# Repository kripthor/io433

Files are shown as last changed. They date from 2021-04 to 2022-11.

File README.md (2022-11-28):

# Project IO433

```
 ___ ___  _ _ ________
|_ _/ _ \| | |__ /__ /
 | | (_) |_  _|_ \|_ \
|___\___/  |_|___/___/
                       
```

## Description

IO433 is an open-source ESP32 (TTGO T-Display) & CC1101 based 433Mhz sniffer. It is currently work in progress.
It can sniff, store, replay, dump and monitor most 433Mhz (currently ASK-OOK only) signals.
These include garage door openers, remote doorbells, sensors and similar devices.

The core of this project aims to be its simplicity, reliability and versatility.
With a couple of ICs and a by 'connecting some wires', or soldering a breakout board, one can start messing around with 433Mhz devices and decode their communications protocols.
It's mainly a proof-of-concept but already encompasses several very useful features.

```bash
│  # The current dir is a platformIO project and can be imported straight from here.
├── arduino  # an example arduino project that implements a remote for some ASK-OOK-PWM signals based on a FS1000A
├── docs     # docs and pictures
├── include  # project helper files 
├── lib    #some needed libraries with specific modifications for this project
├── libsigrokdecode   # a modified PWM decoder that shows bits and nibbles (sigrok/PulseView)
└── src # project main files
```

## Bill of Materials

| Qty. | Description | Obs. |
|---|---|---|
| 1 | ESP32 TTGO T-Display | ESP32 controller with a 1.14" LCD and two buttons for navigation |
| 1 | TI-CC1101 or E07-M1101D | CC1101 based modules for 433Mhz (and other frequencies) communications |
| 1 | io433 PCB| Order a PCB or etch one or just grab some wires :) |
| 1 | Battery | Optional 3.7v battery

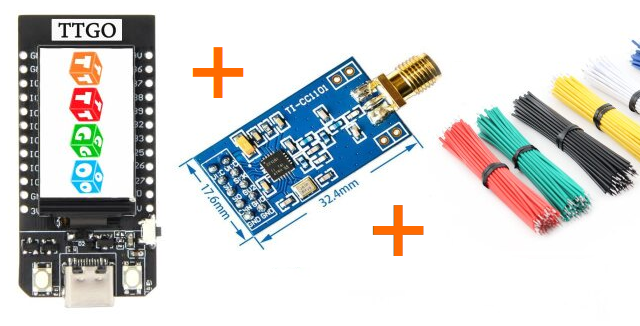
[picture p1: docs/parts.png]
IO433 Parts

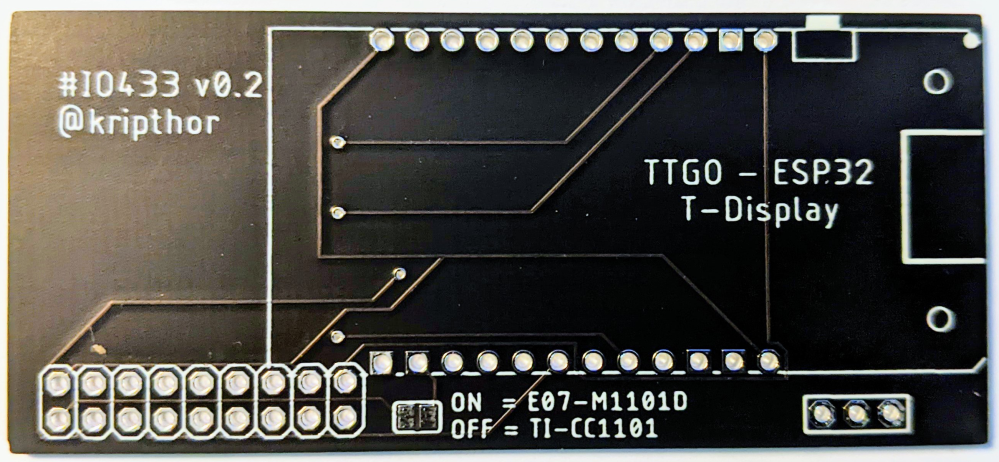
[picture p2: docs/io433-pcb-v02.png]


* All the components can be easily found in the usual online stores such as *AliExpress* ([ESP32 TTGO T-Display](https://aliexpress.com/wholesale?SearchText=ttgo+t+display+esp32)) - [CC1101](https://aliexpress.com/wholesale?SearchText=cc1101)), *Amazon*, *eBay*, etc.
* The breakout pcb and schematics files are under the docs/ directory: 
[IO433 Schematic](docs/breakout.sch)
[IO433 Board](docs/breakout.brd)

## IO433 Wiring

### Prototype photo and assembly suggestion

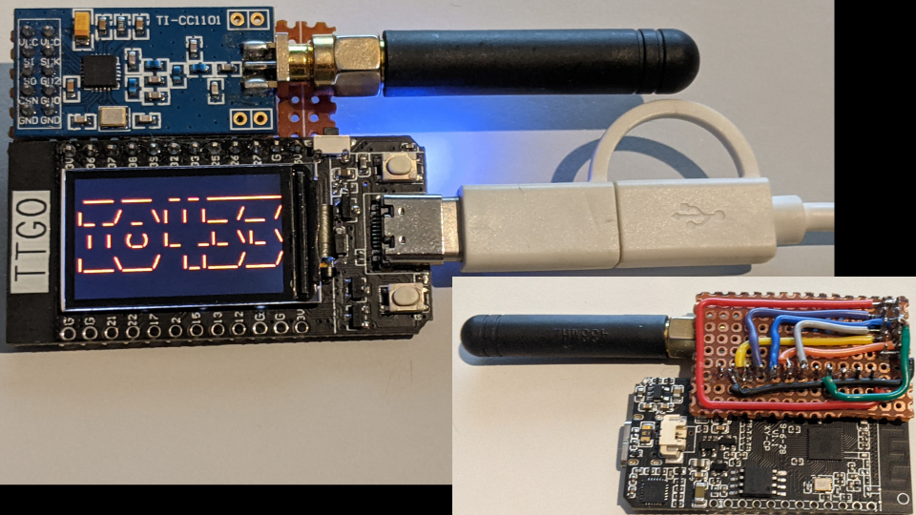
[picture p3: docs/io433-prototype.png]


This is just a suggestion on how to wire the ESP32 and the CC1101. A perforated PCB can be used to make the prototype more sturdy. Or you can just order a pre-fabricated board, like the one bellow:

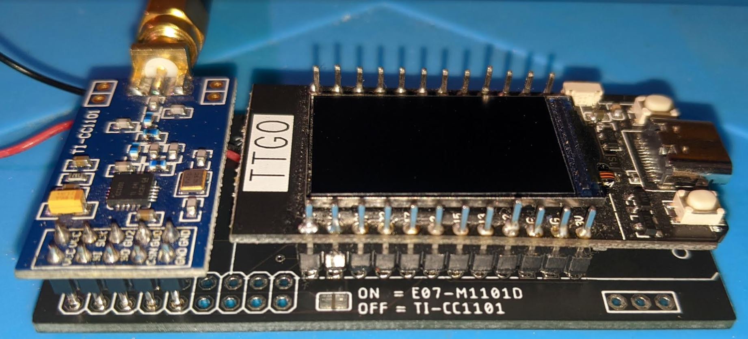
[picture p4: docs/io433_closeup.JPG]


### IO433 Wiring

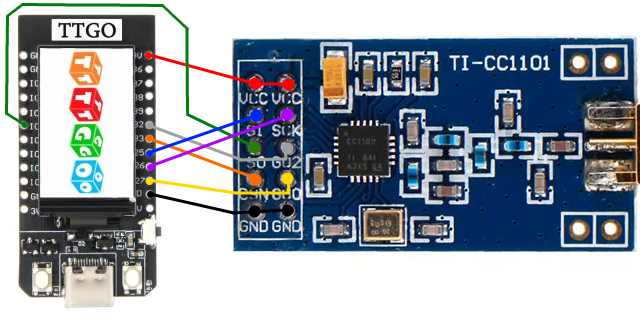
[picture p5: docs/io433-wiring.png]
IO433 Wiring

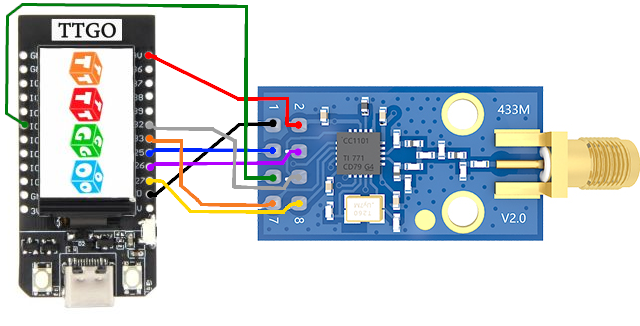
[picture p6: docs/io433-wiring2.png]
IO433 Wiring


Details of the wiring between the ESP32 and TI-CC1101 (above) and the E07-M1101D (below). The pinout choosing is important. If changed, not only the code should change to reflect the new pinout, as one must make sure the corresponding ports on the ESP32 support the I/O operation mode that the code needs. 
* **Important note**: the green wire connects to IO2 on the ESP32, regardless of what you see in some pictures.
* **Important note 2**: You need to change the file ./include/CC1101utils.h to reflect which CC1101 model you are using.

### IO433 PCB Schematics
docs/breakout.sch
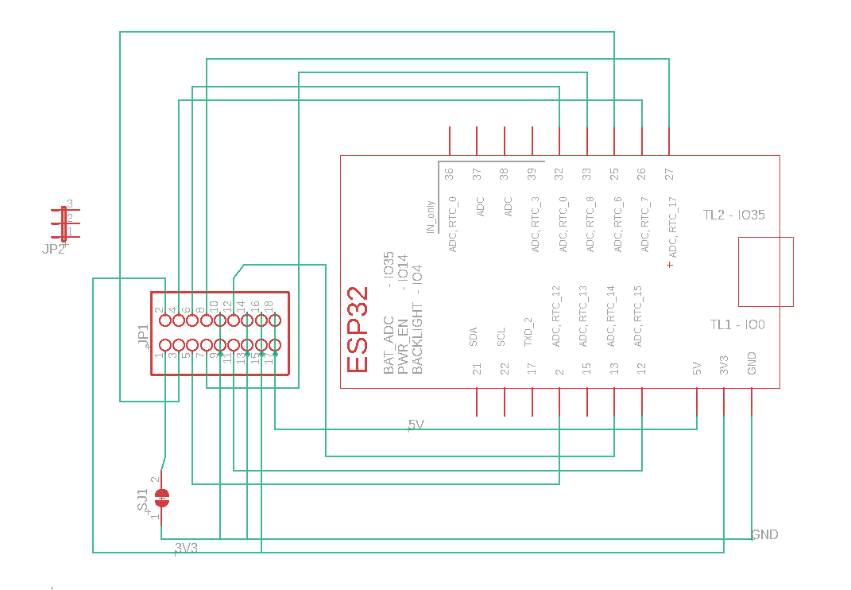
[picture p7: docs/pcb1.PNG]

docs/breakout.brd
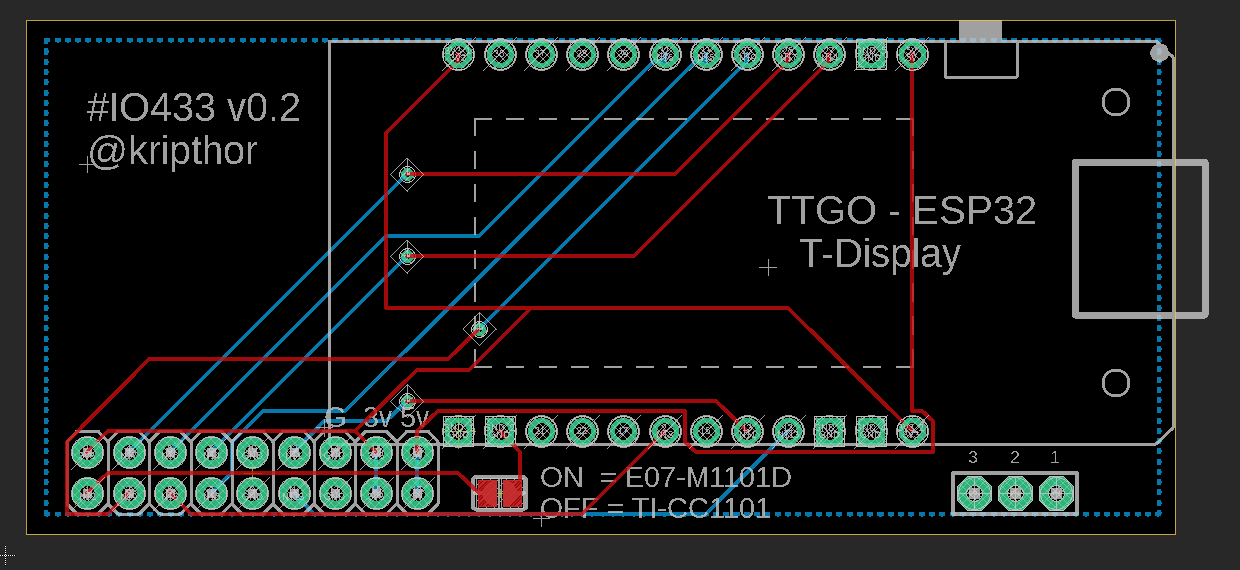
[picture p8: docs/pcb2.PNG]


### Assembly with PCB

Solder the CC1101 based module in the lower leftmost side of the pcb. The E07-M1101D will have 2x4 pins and the TI-CC1101 will have 2x5 pins. If you are using the E07-M1101D, connect the solderable jumper in the lower middle.  

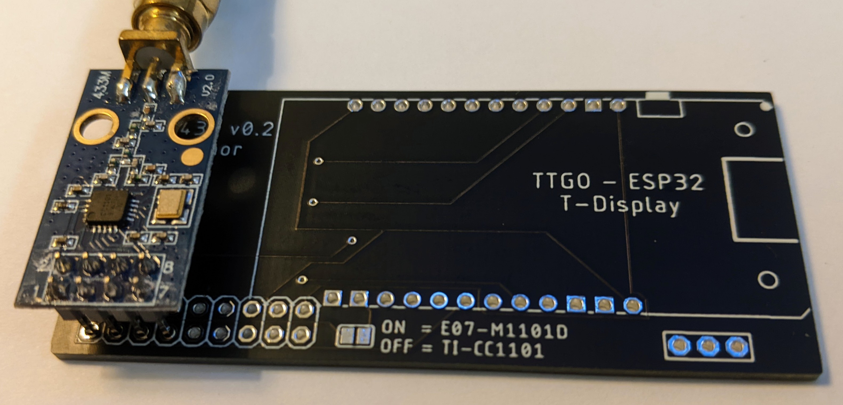
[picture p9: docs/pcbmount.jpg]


Then just solder the ESP32 TTGO module on the PCB. Add a battery or just use the USB cable to power the module. Optionally print the 3D case for your CC1101 module. 
I've made an Youtube video to show how to assemble it in less than half an hour: [IO433 Assembly on Youtube](https://www.youtube.com/watch?v=Nz-Mw6mhYjg)

### Assembly with battery and 3D printed case, no PCB

If you want, you can use the 3D printed case that supports a 902540 720mAh or even a 903048 1800mAh, 3.7V battery (should last for some days)
The full material is listed bellow:

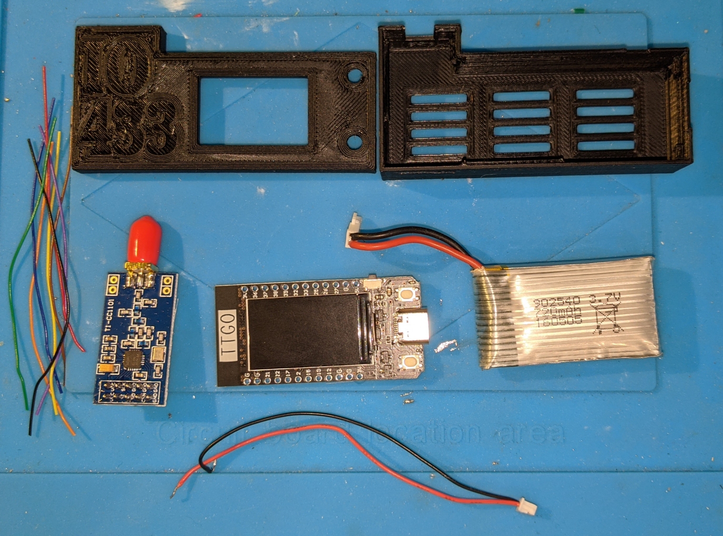
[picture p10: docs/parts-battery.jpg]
IO433 3D case with battery

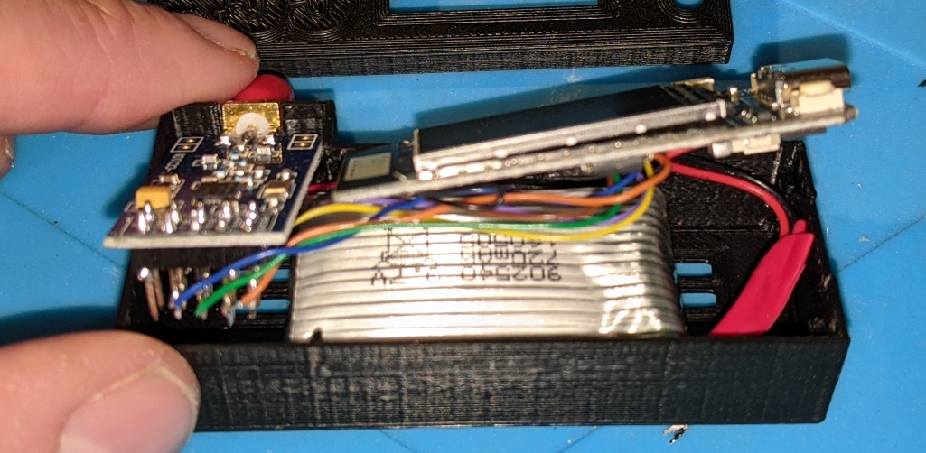
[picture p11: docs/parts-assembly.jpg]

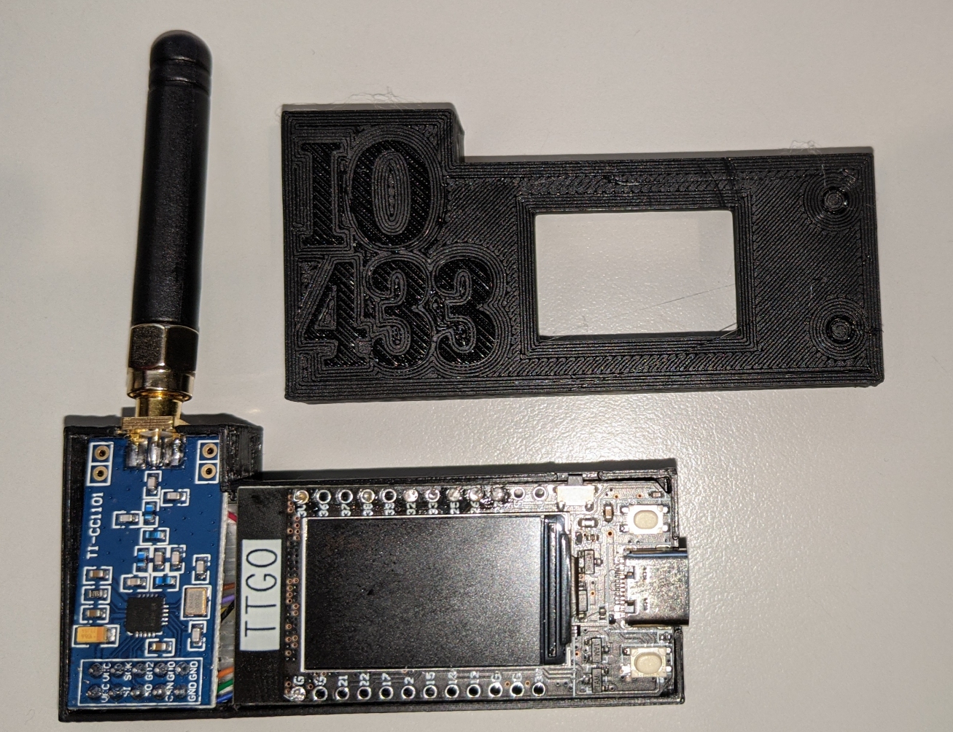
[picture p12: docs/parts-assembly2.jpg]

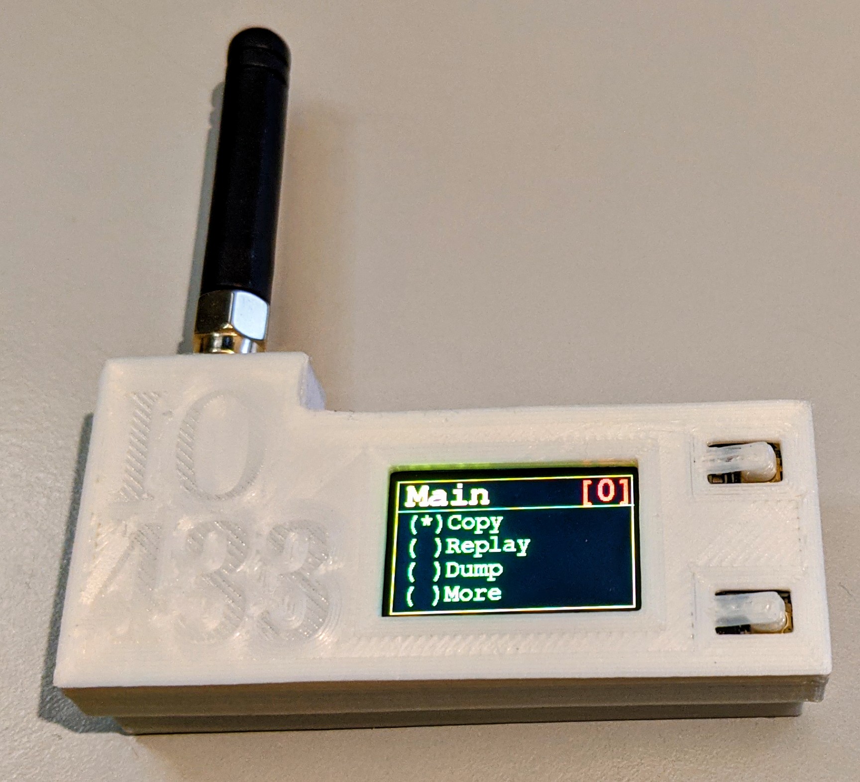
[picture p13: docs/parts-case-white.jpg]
IO433 3D case with battery


### 3D case

NO PCB version:
Tinker/download it from [tinkercad](https://www.tinkercad.com/things/bPiFpUXC7pQ)
or grab the STL from the [docs](docs/IO433.stl)

PCB Version:
Tinker/download, both TI-CC1101 and E07-M1101 versions, from  [tinkercad](https://www.tinkercad.com/things/0qDgP6hPqE1)

## How to flash IO433   

### Using [Platformio](https://platformio.org/)

* Install Visual Studio
* Install PlatformIO from the Extensions (restart)
* Install the Espressif 32 platform from the PlatformIO Embedded tab (restart)
* Clone the repository
* Change the file ./include/CC1101utils.h and uncomment your CC1101 version(either the TICC1101 or the E07M1101D)
* Connect USB-C cable to TTGO
* Build and upload

## How to use it

Plug the ESP32 to a battery or a to a USB-C cable. The current menu structure is the following:

```bash
│ Main
├── Copy   # Copy signal to current memory bank
├── Replay # Replay signal from current memory bank
├── Dump   # Dump current memory bank to screen and serial (fixed 100kbps, for easy analysis on third party software [ex. PulseView])
└── More
    ├── Monitor # Dump raw signal to screen and RSSI info
    ├── Raw Out # Dump current signal to serial as fast as possible (default 1Mbps serial)
    └── About   # About menu
```

## Button behaviour

* UP and DOWN short press, moves between menu items
* UP long press is moves back a level
* DOWN long press enters current submenu or function
* UP or DOWN double press moves back and forward from memory banks (to store/replay multiple signals) 

## Dependencies

This project uses:

 * Button2 lib (which should auto-update on build via platformio.ini)
 * SmartRC-CC1101-Driver-Lib (on /lib, added minor changes for the ESP32 TDisplay)
 * TFT_eSPI (on /lib, added minor changes for the ESP32 TDisplay)

# Improvements

There are many possibilities for improvements:

* Code refactoring. Make SimpleMenu a proper lib.
* Better SPIFFS management
* Configuration menus for changing output data rates and formats
* Configuration menus for CC1101 setup: frequencies, modulations, data rates and bandwidth
* Implement other modulations besides ASK-OOK
* Add upload data files from PC to be replayed
* Add accept from serial and transmit features
* and so forth...

Feel free to clone and play around, as well as to contribute and make a pull request.

## Kudos

* [LSatan](https://github.com/LSatan), for the SmartRC-CC1101-Driver-Lib
* the [TFT_eSPI Library](https://github.com/Bodmer/TFT_eSPI)
* Shameless README.md 'template' rip from [jpdias](https://github.com/jpdias)

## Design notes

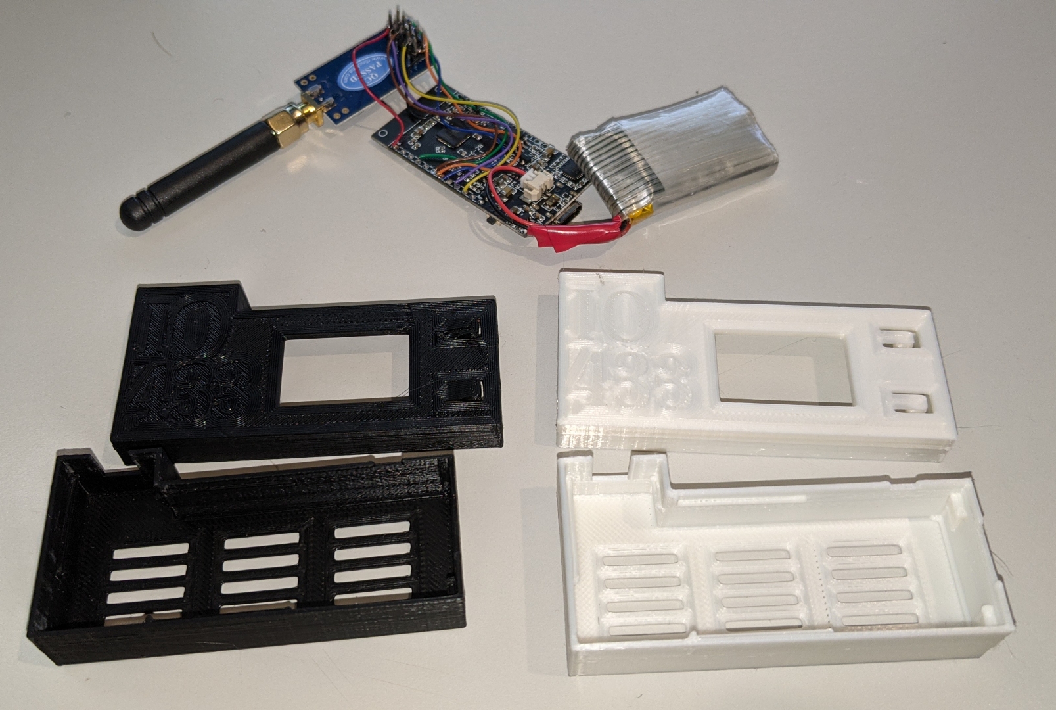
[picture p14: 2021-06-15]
docs/two-cases.jpg

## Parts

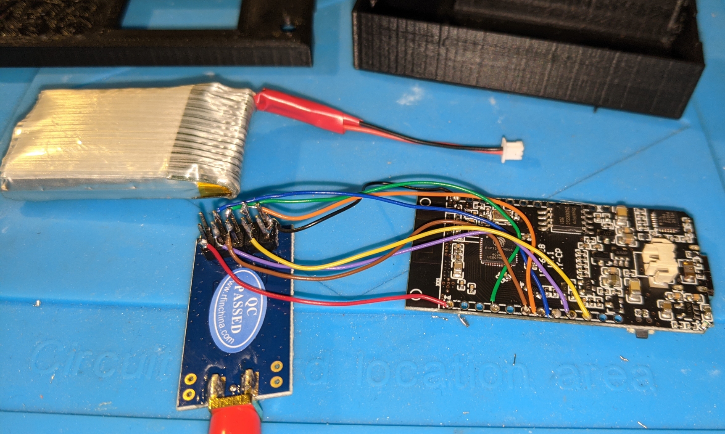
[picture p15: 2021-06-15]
docs/parts-solder.jpg

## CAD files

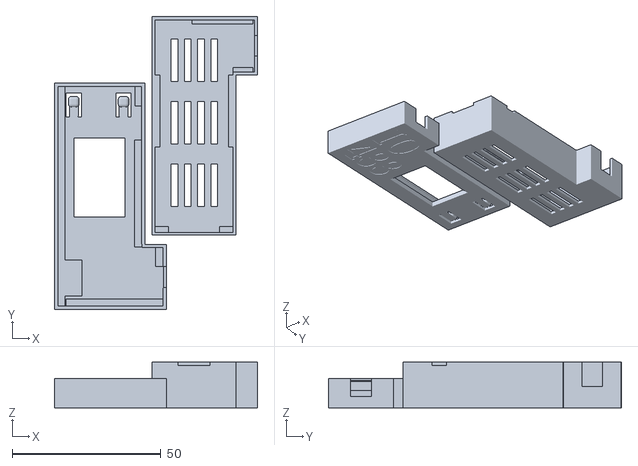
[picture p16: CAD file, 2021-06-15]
docs/IO433.stl
68.4 x 98.6 x 15.4

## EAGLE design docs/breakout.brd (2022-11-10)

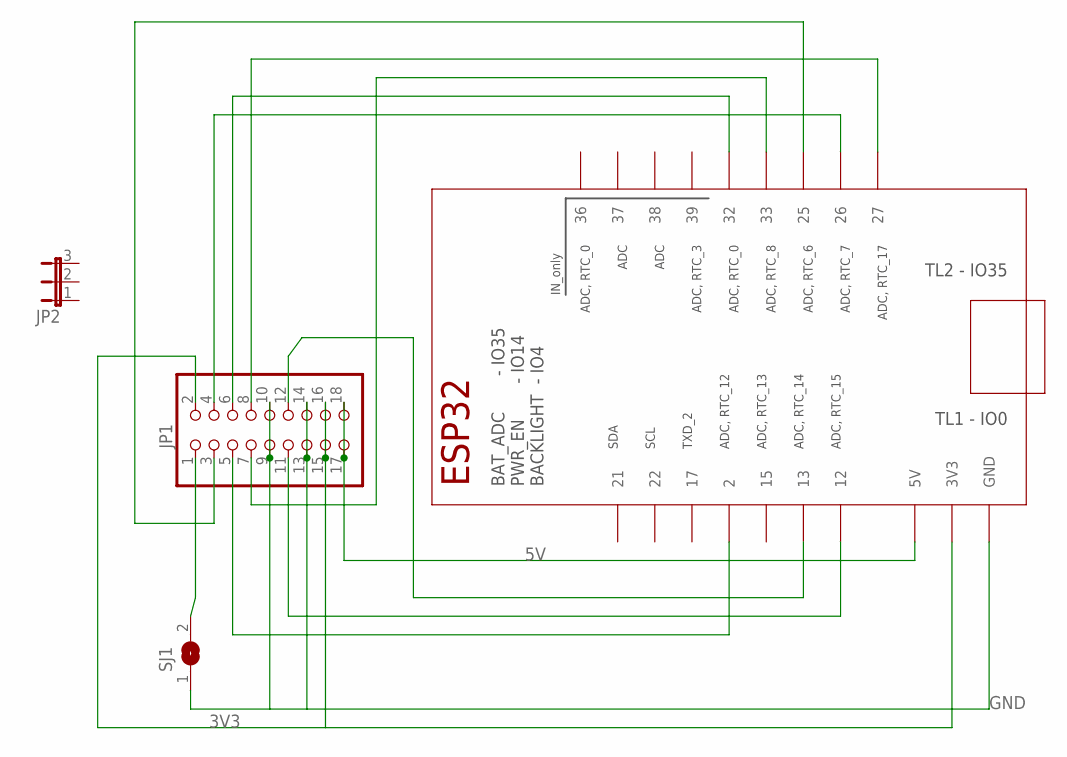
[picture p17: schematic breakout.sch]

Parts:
IC1: TTGO_DISP; TTGO_DISP_DEFAULT
JP1: PINHD-2X9-BIG; 2X09-BIG
JP2: JUMPER3
SJ1: SOLDERJUMPERREFLOW; SOLDERJUMPER_REFLOW

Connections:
3V3: IC1.3V3_1 (3V3), IC1.3V3_2 (3V3), JP1.2, JP1.15, JP1.16
5V: IC1.5V, JP1.17, JP1.18
GND: IC1.GND_1 (GND), IC1.GND_2 (GND), IC1.GND_3 (GND), IC1.GND_4 (GND), IC1.GND_5 (GND), JP1.9, JP1.10, JP1.13, JP1.14, SJ1.1
unnamed: IC1.13, JP1.12
unnamed: JP1.1, SJ1.2
unnamed: IC1.27, JP1.8
unnamed: IC1.33, JP1.7
unnamed: IC1.32, JP1.6
unnamed: IC1.26, JP1.4
unnamed: IC1.2, JP1.5
unnamed: IC1.25, JP1.3
unnamed: IC1.12, JP1.11

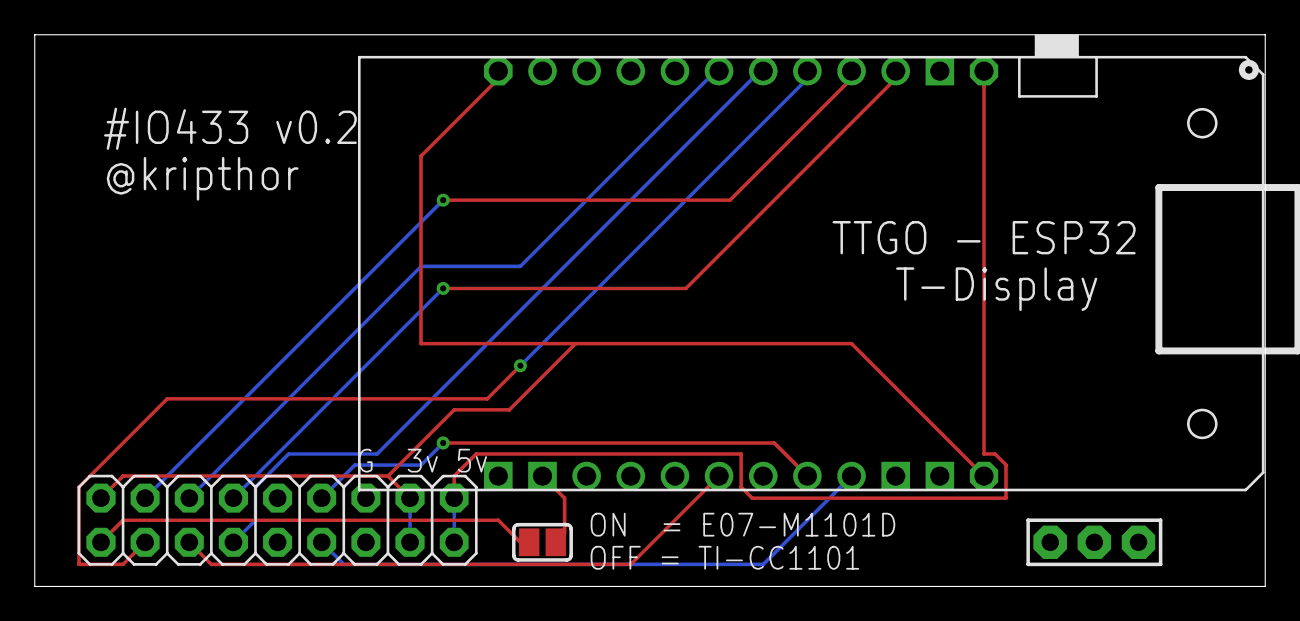
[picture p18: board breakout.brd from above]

Board: 2 copper layers, 70.8 x 31.7 mm, 4 parts (0 on the bottom side), 12 nets.

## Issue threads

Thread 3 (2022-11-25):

esp_deep_sleep.h <--- cannot open source file "esp_deep_sleep.h"

jjdsantos, 2022-11-25:
Hi kripthor. I clone your repository and try to compile, but there are some errors.
e.g. cannot open source file "esp_deep_sleep.h"

Can you help me, please? Thanks a lot!
Julio

 *  Executing task: platformio run

Processing esp32dev (platform: espressif32; board: esp32dev; framework: arduino)
-----------------------------------------------------------------------------------------------------------------------------------------------------------
Verbose mode can be enabled via `-v, --verbose` option
CONFIGURATION: https://docs.platformio.org/page/boards/espressif32/esp32dev.html
PLATFORM: Espressif 32 (5.2.0) > Espressif ESP32 Dev Module
HARDWARE: ESP32 240MHz, 320KB RAM, 4MB Flash
DEBUG: Current (cmsis-dap) External (cmsis-dap, esp-bridge, esp-prog, iot-bus-jtag, jlink, minimodule, olimex-arm-usb-ocd, olimex-arm-usb-ocd-h, olimex-arm-usb-tiny-h, olimex-jtag-tiny, tumpa)
PACKAGES:
 - framework-arduinoespressif32 @ 3.20005.220925 (2.0.5)
 - tool-esptoolpy @ 1.40201.0 (4.2.1)
 - toolchain-xtensa-esp32 @ 8.4.0+2021r2-patch3
LDF: Library Dependency Finder -> https://bit.ly/configure-pio-ldf
LDF Modes: Finder ~ chain, Compatibility ~ soft
Found 35 compatible libraries
Scanning dependencies...
Dependency Graph
|-- Button2 @ 1.6.5
|-- WiFi @ 2.0.0
|-- SmartRC-CC1101-Driver-Lib @ 2.5.6
|   |-- SPI @ 2.0.0
|-- TFT_eSPI @ 2.3.64
|   |-- SPI @ 2.0.0
|   |-- SPIFFS @ 2.0.0
|   |   |-- FS @ 2.0.0
|   |-- FS @ 2.0.0
|-- FS @ 2.0.0
|-- SPIFFS @ 2.0.0
|   |-- FS @ 2.0.0
Building in release mode
Compiling .pio/build/esp32dev/src/main.cpp.o
Archiving .pio/build/esp32dev/lib19b/libButton2.a
Indexing .pio/build/esp32dev/lib19b/libButton2.a
In file included from lib/TFT_eSPI/User_Setup_Select.h:53,
                 from lib/TFT_eSPI/TFT_eSPI.h:39,
                 from src/SimpleMenuNav.h:4,
                 from src/main.cpp:3:
lib/TFT_eSPI/User_Setups/Setup25_TTGO_T_Display.h:17: warning: "TFT_CS" redefined
 #define TFT_CS              5

In file included from lib/TFT_eSPI/User_Setup_Select.h:22,
                 from lib/TFT_eSPI/TFT_eSPI.h:39,
                 from src/SimpleMenuNav.h:4,
                 from src/main.cpp:3:
lib/TFT_eSPI/User_Setup.h:159: note: this is the location of the previous definition
 #define TFT_CS   PIN_D8  // Chip select control pin D8

In file included from lib/TFT_eSPI/User_Setup_Select.h:53,
                 from lib/TFT_eSPI/TFT_eSPI.h:39,
                 from src/SimpleMenuNav.h:4,
                 from src/main.cpp:3:
lib/TFT_eSPI/User_Setups/Setup25_TTGO_T_Display.h:18: warning: "TFT_DC" redefined
 #define TFT_DC              16

In file included from lib/TFT_eSPI/User_Setup_Select.h:22,
                 from lib/TFT_eSPI/TFT_eSPI.h:39,
                 from src/SimpleMenuNav.h:4,
                 from src/main.cpp:3:
lib/TFT_eSPI/User_Setup.h:160: note: this is the location of the previous definition
 #define TFT_DC   PIN_D3  // Data Command control pin

In file included from lib/TFT_eSPI/User_Setup_Select.h:53,
                 from lib/TFT_eSPI/TFT_eSPI.h:39,
                 from src/SimpleMenuNav.h:4,
                 from src/main.cpp:3:
lib/TFT_eSPI/User_Setups/Setup25_TTGO_T_Display.h:19: warning: "TFT_RST" redefined
 #define TFT_RST             23

In file included from lib/TFT_eSPI/User_Setup_Select.h:22,
                 from lib/TFT_eSPI/TFT_eSPI.h:39,
                 from src/SimpleMenuNav.h:4,
                 from src/main.cpp:3:
lib/TFT_eSPI/User_Setup.h:161: note: this is the location of the previous definition
 #define TFT_RST  PIN_D4  // Reset pin (could connect to NodeMCU RST, see next line)

In file included from lib/TFT_eSPI/User_Setup_Select.h:53,
                 from lib/TFT_eSPI/TFT_eSPI.h:39,
                 from src/SimpleMenuNav.h:4,
                 from src/main.cpp:3:
lib/TFT_eSPI/User_Setups/Setup25_TTGO_T_Display.h:36: warning: "SPI_FREQUENCY" redefined
   #define SPI_FREQUENCY  40000000   // Maximum for ILI9341

In file included from lib/TFT_eSPI/User_Setup_Select.h:22,
                 from lib/TFT_eSPI/TFT_eSPI.h:39,
                 from src/SimpleMenuNav.h:4,
                 from src/main.cpp:3:
lib/TFT_eSPI/User_Setup.h:322: note: this is the location of the previous definition
 #define SPI_FREQUENCY  27000000

In file included from lib/TFT_eSPI/User_Setup_Select.h:53,
                 from lib/TFT_eSPI/TFT_eSPI.h:39,
                 from src/SimpleMenuNav.h:4,
                 from src/main.cpp:3:
lib/TFT_eSPI/User_Setups/Setup25_TTGO_T_Display.h:39: warning: "SPI_READ_FREQUENCY" redefined
 #define SPI_READ_FREQUENCY  6000000 // 6 MHz is the maximum SPI read speed for the ST7789V

In file included from lib/TFT_eSPI/User_Setup_Select.h:22,
                 from lib/TFT_eSPI/TFT_eSPI.h:39,
                 from src/SimpleMenuNav.h:4,
                 from src/main.cpp:3:
lib/TFT_eSPI/User_Setup.h:328: note: this is the location of the previous definition
 #define SPI_READ_FREQUENCY  20000000

Compiling .pio/build/esp32dev/lib216/WiFi/WiFiSTA.cpp.o
Compiling .pio/build/esp32dev/lib216/WiFi/WiFiScan.cpp.o
Compiling .pio/build/esp32dev/lib216/WiFi/WiFiServer.cpp.o
Compiling .pio/build/esp32dev/lib216/WiFi/WiFiUdp.cpp.o
In file included from src/main.cpp:3:
src/SimpleMenuNav.h:9: warning: "LONGCLICK_MS" redefined
 #define LONGCLICK_MS 300

In file included from src/SimpleMenuNav.h:2,
                 from src/main.cpp:3:
.pio/libdeps/esp32dev/Button2/src/Button2.h:21: note: this is the location of the previous definition
 #define LONGCLICK_MS 200

src/main.cpp:5:10: fatal error: esp_deep_sleep.h: No such file or directory

************************************************************************
* Looking for esp_deep_sleep.h dependency? Check our library registry!
*
* CLI  > platformio lib search "header:esp_deep_sleep.h"
* Web  > https://registry.platformio.org/search?q=header:esp_deep_sleep.h
*
************************************************************************

 #include "esp_deep_sleep.h"
          ^~~~~~~~~~~~~~~~~~
compilation terminated.
Compiling .pio/build/esp32dev/lib4e4/SPI/SPI.cpp.o
Compiling .pio/build/esp32dev/lib7da/SmartRC-CC1101-Driver-Lib/ELECHOUSE_CC1101_SRC_DRV.cpp.o
*** [.pio/build/esp32dev/src/main.cpp.o] Error 1
=============================================================== [FAILED] Took 3.04 seconds ===============================================================

 *  The terminal process "platformio 'run'" terminated with exit code: 1.
 *  Terminal will be reused by tasks, press any key to close it.

vreabernardo, 2022-11-28:
esp_deep_sleep.h was [deprecated in IDF](https://github.com/espressif/esp-idf/commit/d2acf1ce77a2883e519ef57da5ff3e45bb0d6bbe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) in favor of esp_sleep.h which has [already been updated in Arduino](https://github.com/espressif/arduino-esp32/commit/39fb8c30440a4abd5fe0e2c87609ba6798ae8013)

Just replace:
 `#include "esp_deep_sleep.h"`
For:
`#include "esp_sleep.h"`

and the functions:
`esp_deep_sleep_pd_config()`
For:
`esp_sleep_pd_config()`

and it should work

jjdsantos, 2022-11-28:
Thank you for your explanation and suggestions, @vreabernardo .

Thank you so much for your support and help, @kripthor .

I think that we can close this issue. Best, Julio

kripthor, 2022-11-28:
Hi @vreabernardo! I've noticed you have fixed the issue and made a pull request. At the same time, I was working on the issue with Julio and also fixed the issue. Many thanks anyway! :)

Closed 2022-11-28.

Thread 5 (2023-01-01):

Files for PCB assembly

voltagex, 2023-01-01:
Hi,
Is it possible to get files that JLCPCB would accept to produce an assembled board?

Thanks in advance.

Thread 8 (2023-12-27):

Add Time jamming signal ...

avrilboy, 2023-12-27:
Thanks alot can you add the time jamming for the signals for exampel turn the device and get all the signals comming for 5sec or 10sec and replay alls...and add the jammer to the program?
Thanks

lmichoux, 2024-03-02:
Hi I made the jam feature.
Have a look here :
https://github.com/lmichoux/io433

avrilboy, 2024-03-07:
> Hi I made the jam feature. Have a look here : https://github.com/lmichoux/io433

I need the signals time more than 1sec for example i turne the device but more than signals comming and i cant replay the current i need time jaming signal more than 1 sec anf increase the time  for 5 or 10 or more...a d replay all in ome click or the same signals not again saved...thanks alot

avrilboy, 2024-03-07:
Is it possible to transfer the rtl.sdr signals jamming in to this device and replay? And help how?

lmichoux, 2024-03-07:
The jam feature I added in my fork is to jam for as as long as you need, jammed signal is random values (not recorded from sdr) . when you want to stop, press a key (the up key in my case)
if (SMN_isUpButtonPressed()) return; Adding a timed jam is another feature. also you cannot record while jamming with same device, idealy you need 2 devices separated from some distance, or receiver will get jammed signal.

rverzinkevicius, 2024-08-07:
> The jam feature I added in my fork is to jam for as as long as you need, jammed signal is random values (not recorded from sdr) . when you want to stop, press a key (the up key in my case) if (SMN_isUpButtonPressed()) return; Adding a timed jam is another feature. also you cannot record while jamming with same device, idealy you need 2 devices separated from some distance, or receiver will get jammed signal.

Actually you should use break instead of return.

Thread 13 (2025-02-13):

HELP ME...2FSK

MacRF, 2025-02-13:
I wish it worked for 2fsk too.
the code works fine in ASK/ook modulation, but if you set the parameters for 2fsk it doesn't sample the signals well and the copy stops immediately. Is there any expert who can help to implement this feature?

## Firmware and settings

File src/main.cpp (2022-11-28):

#include "spiffsutils.h"
#include "CC1101utils.h"
#include "SimpleMenuNav.h"
#include "WiFi.h"
#include "esp_sleep.h"
#include "esp_bt_main.h"
#include "esp_bt.h"
#include "esp_wifi.h"
#include "driver/adc.h"


#define LOOPDELAY 20
#define HIBERNATEMS 30*1000
#define BUFSIZE 2048
#define REPLAYDELAY 0
// THESE VALUES WERE FOUND PRAGMATICALLY
#define RESET443 64000 //32ms
#define WAITFORSIGNAL 32 // 32 RESET CYCLES
#define MINIMUM_TRANSITIONS 32
#define MINIMUM_COPYTIME_US 16000
#define DUMP_RAW_MBPS 0.1 // as percentage of 1Mbps, us precision. (100kbps) This is mainly to dump and analyse in, ex, PulseView
#define BOUND_SAMPLES false

//ONLY USING ONE BUFFER FOR NOW, MUST BE REFACTORED TO SUPPORT MORE (AND MOVE TO SPIFFS)
uint16_t signal433_store[MAXSIGS][BUFSIZE];
uint16_t *signal433_current = signal433_store[0];


int delayus = REPLAYDELAY;
long lastCopyTime = 0;

int trycopy() {
  int i;
  Serial.println("Copying...");
  uint16_t newsignal433[BUFSIZE];
  memset(newsignal433,0,BUFSIZE*sizeof(uint16_t));
  byte n = 0;
  int64_t startus = esp_timer_get_time();
  int64_t startread;
  int64_t dif = 0;
  int64_t ttime = 0;
  for (i = 0; i < BUFSIZE; i++) {
    startread = esp_timer_get_time();
    dif = 0;
    //WAIT FOR INIT
    while (dif < RESET443) {
      dif = esp_timer_get_time() - startread;
      if (CCAvgRead() != n) {
        break;
      }
    }
    if (dif >= RESET443) {
       newsignal433[i] = RESET443;
      //if not started wait...
      if (i == 0) {
        i = -1;
        ttime++;
        if (ttime > WAITFORSIGNAL) {
          Serial.println("No signal detected!");
          return -1;
        }
      }
      else {
        ttime++;
        if (ttime > WAITFORSIGNAL) {
          Serial.println("End of signal detected!");
          break;
        }
        /*
        Serial.println("End of signal!");
        break;*/
      }
    }
    else {
     newsignal433[i] = dif;
     n = !n;
    }
  }
  
  int64_t stopus = esp_timer_get_time();
  Serial.print("Copy took (us): ");
  lastCopyTime = (long)(stopus - startus);
  Serial.println(lastCopyTime , DEC);
  Serial.print("Transitions: ");
  Serial.println(i);
  memcpy(signal433_current,newsignal433,BUFSIZE*sizeof(uint16_t));
  return i;
}

void copy() {
  int i, transitions = 0;
  lastCopyTime = 0;
  CCInit();
  CCSetRx();
  delay(50);
  //FILTER OUT NOISE SIGNALS (too few transistions or too fast)
  while (transitions < MINIMUM_TRANSITIONS && lastCopyTime < MINIMUM_COPYTIME_US) {
    transitions = trycopy();
    if (SMN_isUpButtonPressed()) return;
  }
  //CLEAN LAST ELEMENTS
  for (i=transitions-1;i>0;i--) {
    if (signal433_current[i] == RESET443) signal433_current[i] = 0;
    else break;
  }
  if (BOUND_SAMPLES) {
    signal433_current[0] = 200;
    if (i < BUFSIZE) signal433_current[i+1] = 200;
  }
  
  String fname = "/" + String(pcurrent) +".bin";
  storeSPIFFS(fname.c_str(),signal433_current,BUFSIZE);
}



void replay (int t) {
  int i;
  unsigned int totalDelay = 0;
  CCInit();
  CCSetTx();
  delay(50);
  int64_t startus = esp_timer_get_time();
  while (t-- > 0) {
    byte n = 0;
    for (i = 0; i < BUFSIZE; i++) {
      CCWrite(n);
      totalDelay = signal433_current[i]+delayus;
      delayMicroseconds(totalDelay);
      if (signal433_current[i] < RESET443) n = !n;
    }
     CCWrite(0);
  }
  CCSetRx();
  
  int64_t stopus = esp_timer_get_time();
  Serial.print("Replay took (us): ");
  Serial.println((long)(stopus - startus), DEC);

}


void replay () {
  replay(1);
}

void dump () {
  long ttime = 0;
  int trans = 0;
  int i,j;
  int n = 0;
  Serial.println("Dump transition times: ");
  for (i = 0; i < BUFSIZE; i++) {
    if (signal433_current[i] <= 0) break;
    if (i > 0) Serial.print(",");
    Serial.print(signal433_current[i]);
    ttime += signal433_current[i];
    if (signal433_current[i] != RESET443) {
      n = !n;
      trans++;
    }
  }
  Serial.print("\nTotal time (us): ");
  Serial.println(ttime, DEC);
  Serial.print("Transitions 0/1: ");
  Serial.println(trans, DEC);
  
  Serial.print("Dump raw (");
  Serial.print(DUMP_RAW_MBPS);
  Serial.println("Mbps):");
  
  n = 0;
  long samples = 0;
  for (i = 0; i < BUFSIZE; i++) {
    if (signal433_current[i] <= 0) break;
    for (j = 0; j < signal433_current[i]*DUMP_RAW_MBPS; j++) {
       samples++;
       if (n) Serial.write(124);
       else Serial.write(46);
       Serial.flush();
    }
    if (signal433_current[i] != RESET443) n = !n;
  }
  Serial.print("\nTotal samples: ");
  Serial.println(samples);
  SMN_dump(signal433_current,BUFSIZE,RESET443);
 
}


// THIS IS OBVIOUSLY SLOW
void rawout() {
  CCInit();
  CCSetRx();
  delay(50);

  byte b;
  bool endloop = false;
  long t = 0;
  long start = millis();
  while(!endloop) {
    b = CCAvgRead();
    //BOTTLENECK ON SERIAL WRITE... OUT VALUES ARE BOTH ASCII AND EASY TO FILTER IN PULSEVIEW
    if (b) Serial.write(124);
    else Serial.write(46);
    Serial.flush();
    t++;
    if (SMN_isAnyButtonPressed()) {
      endloop = true;
    }
  }
  long tt = millis() - start;
  
  Serial.print("\n Total time(ms): ");
  Serial.print(tt);
  Serial.print("\n Total bits: ");
  Serial.print(t);
  Serial.print("\n bits/sec: ");
  Serial.println((t*1.0)/(tt/1000.0));
}

// THIS IS OBVIOUSLY NOT REAL TIME
void monitormode() {
  CCInit();
  CCSetRx();
  delay(50);
 
  int k = 1;
  int i = 0;
  int rssi = 0;
  int maxrssi = -999;
  int minrssi = 0;
  int oldy = 0;
  int newy = 0;

  tft.fillScreen(TFT_BLACK);
  tft.drawRect(0, 0, WIDTH-1, HEIGHT-1, TFT_WHITE);
  tft.setFreeFont(FMB9);
  tft.setTextColor(TFT_RED, TFT_WHITE);
  
  delay(200);
  while(true) {
    i = CCAvgRead();
    tft.drawLine(k, HEIGHT/2, k, HEIGHT-16, TFT_BLACK);
    if (i) newy =  HEIGHT/2;
    else newy = HEIGHT-16;
    tft.drawLine(k,oldy,k,newy, TFT_GREEN);
    oldy=newy;
    if (k%50 == 0) rssi = ELECHOUSE_cc1101.getRssi();
    maxrssi = max(maxrssi,rssi);
    minrssi = min(minrssi,rssi);
    delayMicroseconds(200);
    if (k++ >= WIDTH-5) {
      tft.drawString(" RSSI: M      m      ",7,10 , GFXFF);
      tft.drawString(String(maxrssi),10*10,10 , GFXFF);
      tft.drawString(String(minrssi),18*10,10 , GFXFF);
      k = 1;
      maxrssi = -999;
      minrssi = 0;
      if (SMN_isUpButtonPressed()) return;
      while (SMN_isDownButtonPressed()) delay(100);
    }
  }
}


void setup() {
  
  CCInit();
  CCSetRx();
  Serial.begin(1000000);

  ////////////// DEFINE THE MENUS ////////////////
  /*
  MAIN
  |-> COPY
  |-> REPLAY
  |-> DUMP
  |-> MORE
      |-> MONITOR
      |-> RAW OUT
      |-> ABOUT
  */

  SimpleMenu *menu_main = new SimpleMenu("Main");
  SimpleMenu *menu_copy = new SimpleMenu("Copy",menu_main,copy);
  SimpleMenu *menu_replay = new SimpleMenu("Replay",menu_main,replay);
  SimpleMenu *menu_dump = new SimpleMenu("Dump",menu_main,dump);
  SimpleMenu *menu_more = new SimpleMenu("More",menu_main,NULL);

  SimpleMenu *menu_monitor = new SimpleMenu("Monitor",menu_more,monitormode);
  SimpleMenu *menu_load = new SimpleMenu("Raw Out",menu_more,rawout);
  SimpleMenu *menu_about = new SimpleMenu("About",menu_more,SMN_screensaver);


  menu_dump->alertDone = false;
  menu_monitor->alertDone = false;
  menu_about->alertDone = false;
  SMN_initMenu(menu_main);
 
  //// ENSURE RADIO OFF (FOR LESS INTERFERENCE?)
  esp_bluedroid_disable();
  esp_bt_controller_disable();
  esp_wifi_stop();
  //adc_power_off();

  if(!SPIFFS.begin(FORMAT_SPIFFS_IF_FAILED)){
    Serial.println("SPIFFS Mount Failed");
    return;
  }

  Serial.println("List SPIFFS:");
  listSPIFFS("/", 1);
  Serial.println("Loading files...");
  
  for (int f=0;f<MAXSIGS;f++) {
    String fname = "/" + String(f) +".bin";
    loadSPIFFS(fname.c_str(),signal433_store[f],BUFSIZE);
  }
  

  //NEED TO DOUBLE CHECK THIS MATH
  String vbat = String((float)( analogRead(34) / 4095.0 * 2 * 3.3 * 1.1));
  SMN_alert("Bat = \n"+vbat+"v",100,1500);
}


void loop() {
  SMN_loop(); //MUST BE REGULARY CALLED.
  delay(LOOPDELAY);
  signal433_current = signal433_store[pcurrent];

  if (SMN_idleMS() > HIBERNATEMS) {
    SMN_alert("SLEEPING...",100,3000);
    esp_sleep_enable_ext0_wakeup(GPIO_NUM_0,0);
    
    esp_sleep_pd_config(ESP_PD_DOMAIN_RTC_PERIPH, ESP_PD_OPTION_AUTO);
    esp_sleep_pd_config(ESP_PD_DOMAIN_RTC_SLOW_MEM, ESP_PD_OPTION_AUTO);
    esp_sleep_pd_config(ESP_PD_DOMAIN_RTC_FAST_MEM, ESP_PD_OPTION_AUTO);
    esp_sleep_pd_config(ESP_PD_DOMAIN_XTAL, ESP_PD_OPTION_AUTO);
    ELECHOUSE_cc1101.goSleep();
    esp_deep_sleep_start();
  }
}

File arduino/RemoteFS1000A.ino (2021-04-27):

#include <EEPROM.h>

#define LED LED_BUILTIN

//PINS FOR THE FS1000A
#define OUTVIN 9
#define OUTDATA A0
#define OUTGND 10

//PWM SIGNAL CONSTANTS
#define REPEATSIGNAL 8
#define SIGNAL_PERIOD 1200
#define SIGNAL_TIME SIGNAL_PERIOD/3
#define SIGNAL_PREAMBLE 2300
#define SIGNAL_INTERVAL 24400

// Define some time critical functions to avoid function calls.
// If needed, this can be optimized further. But works well as is for above timings.

#define SENDWAIT(B,T) digitalWrite(OUTDATA, B); delayMicroseconds(T);

// There is a 66% (active low) duty cycle for '1' and 33% for '0'
// Rougly translates to: 001 -> encodes '1'  /  011 -> encodes '0'
#define SENDBIT(B,T) SENDWAIT(0,T); SENDWAIT(!B,T); SENDWAIT(1,T); 

// ddddddd(gate id?) 7f(button pressed:7f/bf/df/ef) 98fb('rolling key')
// You need to change to your own gate ID!
//                     d        d        d        d        d         d        d        7        f       9       8        f        b
byte signal433[] = {1,1,0,1, 1,1,0,1, 1,1,0,1, 1,1,0,1, 1,1,0,1, 1,1,0,1, 1,1,0,1, 0,1,1,1, 1,1,1,1, 1,0,0,1, 1,0,0,0, 1,1,1,1, 1,0,1,1};
byte signalLength = sizeof(signal433)/sizeof(signal433[0]);


void blinky() {
  int i = 0;
  while (i++ <= 3) {
     digitalWrite(LED, HIGH);
     delay(75);
     digitalWrite(LED, LOW);
     delay(75);
   }
}

void randomizeKey() {
   // 'randomly' change 'rolling key'
  randomSeed(EEPROM.read(0) ^ EEPROM.read(1));
  byte r0 = (byte)random(255);
  byte r1 = (byte)random(255);
  EEPROM.write(0,r0);
  EEPROM.write(1,r1);
  for (int j=0;j<8;j++) {
    signal433[36+j] = ((r0>>j)&1);
    signal433[44+j] = ((r1>>j)&1);
  };
}


void setup() {
  Serial.begin(115200);
  pinMode(OUTVIN, OUTPUT);
  pinMode(OUTGND, OUTPUT);
  pinMode(OUTDATA, OUTPUT);
  pinMode(LED, OUTPUT);
  digitalWrite(OUTVIN,HIGH);
  digitalWrite(OUTGND,LOW);
  digitalWrite(OUTDATA,LOW);
  randomizeKey();
}

void loop() {
  int i,t;
  for (t=0; t<REPEATSIGNAL;t++){   
    
      //SEND PREAMBLE
      SENDWAIT(1,SIGNAL_PREAMBLE);

      //SEND BITS
      for (i = 0; i < signalLength; i++){
        SENDBIT(signal433[i], SIGNAL_TIME);
      }
      
      //WAIT SOME INTERVAL
      SENDWAIT(0,SIGNAL_INTERVAL); 
  }
  
  // A PAUSE AND A BLINK
  blinky();
  delay(2000);
}

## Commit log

2021-04-26 Example arduino code
2021-04-27 Added sigrok PWM filter. Added comments.
2021-04-29 Added deep sleep on idle for battery devices. V0.2
2021-06-15 3D case and pics
2021-06-15 Fixed assembly2 link
2021-06-15 Full assembly pic
2021-06-15 link to stl
2021-07-05 Improved deep sleep to around 9mA
2022-11-14 CC1101utils had the defines switched for TI-CC1101 and the E07-M1101D
2022-11-14 New wiring
2022-11-28 Updated esp_deep_sleep to esp_sleep, minor code changes. Please update your platformio Espressif libraries to the latest version if you have problems compiling.
    [main.cpp]

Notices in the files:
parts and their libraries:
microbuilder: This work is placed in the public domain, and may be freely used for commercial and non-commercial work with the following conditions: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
